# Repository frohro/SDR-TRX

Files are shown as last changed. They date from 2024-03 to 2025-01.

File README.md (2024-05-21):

# SDR-TRX Digital Modes Transceiver, 2023-2024
## Philosophy and Design Goals
This SDR is a prototype hardware platform to assist in developing a low-cost transceiver for digital modes (FT8, JSTcall, WSPR, CW, etc) that do not require linear amplification like SSB.  This is designed for amateur radio enthusiasts who view their hobby as an avenue for experimenting, who like building things, and have an interest in HF radio propagation.  The idea is to use a laptop and mainstream (actively maintained) existing software as the display and for the DSP needed.  The hardware described here will fill out the rest of the transceiver.  The assumption is that most hams will have a PC of some kind already, and this is an easy and cheap way to get on the air using the digital modes and their PC.
I am also using this as a platform to demonstrate to my students how to do an electronic design project.  It is hoped a transceiver based on this prototype platform will be inexpensive enough that third-world hams or those with few funds to spend on their hobby would find it attractive.  JLCPCB built five of these for me for a little over $100.  This project is built using designs previously published and would not be possible without them.  The next section is meant to be a short review of some of the projects I found especially useful.
### Previous Work
#### Especially Relevant Work
* [WSJT-Transceiver](https://github.com/agustinmartino/wsjt_transceiver/blob/master/README.md)
* [Quisk SDR Software](https://james.ahlstrom.name/quisk/)
* [WSJT-X Low S/N Digital Mode Decoding Software](https://wsjt.sourceforge.io/)
* [Fldigi](http://www.w1hkj.com/FldigiHelp/index.html)
* [DL2MAN Sandwich](https://dl2man.de/sample-page/)
* [PE1NNZ uSDX](https://github.com/threeme3/usdx)
* [A Comparison of Affordable Self-Assembled SDR Receivers](https://fweb.wallawalla.edu/~frohro/ClassHandouts/Electronics/A%20Comparison%20of%20Affordable,%20Self-Assembled%20%20Software-Defined%20Radio%20Receivers%20Using%20Quadrature%20Sampling%20Down-Conversion.pdf)
* [QRP Labs QDX Transceiver](https://www.qrp-labs.com/qdx.html) (This transceiver is quite similar.)
#### More General but Useful Work
*  [Easy-Transceiver](https://github.com/kholia/Easy-Transceiver])
* [Etherkit JTEncode](https://github.com/etherkit/JTEncode)
* [Etherkit Si5351](https://github.com/etherkit/Si5351Arduino)

###
The basic block diagram showing how this SDR interfaces with a PC is shown below.  (Sorry the photos do not show up on GitHub's README here.  To see them, download the progress notes here: https://github.com/frohro/SDR-TRX/blob/main/SDR-TRX-Readme-Progress-Notes.html and then open them in your browser, or get the iPython Progress Notes for a more up to date version and use JupyterLab or similar tool to read them.)

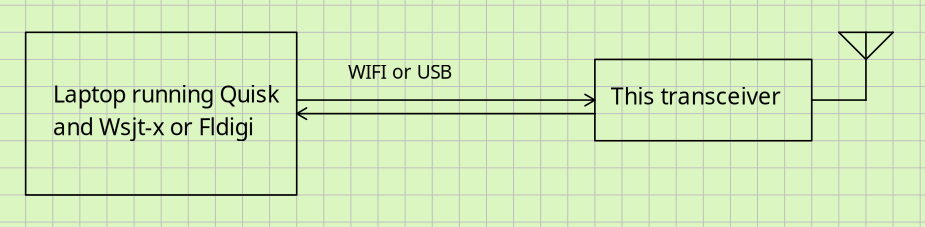
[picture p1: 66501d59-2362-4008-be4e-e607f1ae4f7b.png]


A clone of the Silicon Labs, Si5351a, the MS5351M is used as the local oscillator for the QSD down converter.  The resultant audio frequency data is sent to the PC where Quisk demodulates it and sends it on to WSJT-X or Fldigi for decoding.  The MS5351M's third oscillator is used to generate the digital signals on transmit.  These signals are amplified by a class E circuit for the 20-meter band.  Throughout the unit, there are features that provide stepping stones toward the final goal.  For example, an output is provided to allow the sound data to be sent to the PC where a sound card on the PC converts the sound signal to digital samples.  A Raspberry Pi Pico or Pico W is used on the SDR to control the MS5351M local oscillator and exciter, sample the receiver audio data using a PCM1808 ADC, and send the sampled data to the PC for processing.  It also receives transmit data from the PC to allow transmission of the digital signals desired.

The Kicad project SDR-TRX contains the hardware documentation, including the schematic diagram and the printed circuit board.  The software is still in development.

##  Transmitter 
The MS5351M, a Si5351a clone, generates a digitally transmitted signal (and the harmonics you expect) on its third output.  It is used to drive a set of CMOS inverters that in turn drive a MOSFET class E amplifier for 20 meters. 

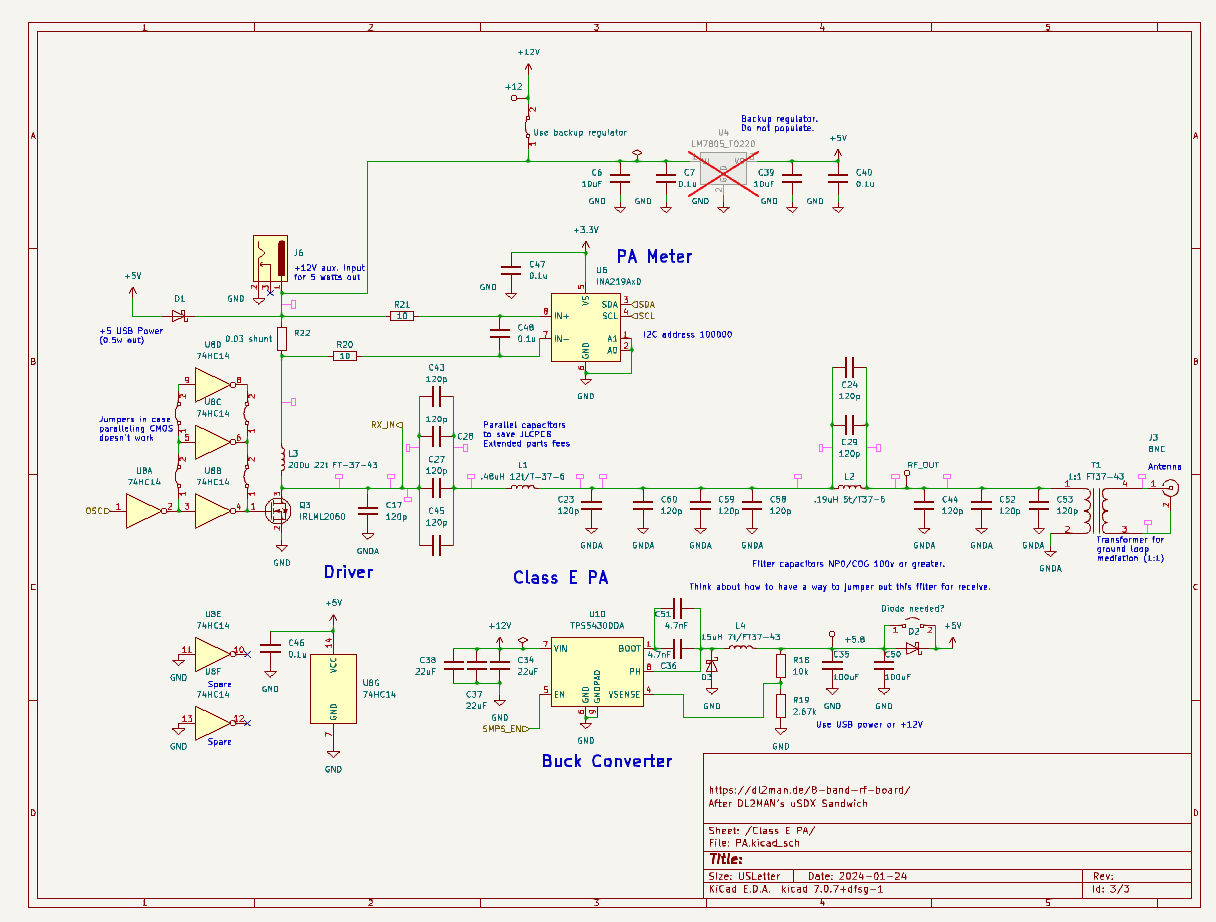
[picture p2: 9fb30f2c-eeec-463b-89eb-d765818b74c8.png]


### Class E Amplifier
The design started with the DL2MAN sandwich Class E amplifier for 20 meters.  LTspice was employed to try and minimize the number of values of Extended Parts capacitors needed from JLCPCB while still maintaining a decent efficiency, power output, and harmonic attenuation.  The value of the capacitor that seemed to be best was a 120 pF 100V 1% COG multilayer monolithic capacitor.  We paralleled a bunch to make the amplifier we ended up with.  It was chosen first for harmonic suppression, second for power output, and lastly for efficiency, with the constraint of using only one value of capacitor.  The simulation has about 50 dB of harmonic attenuation, about a watt of output, and an efficiency of 75%.  See the simulation below which is called Class E.asc in the Simulation folder.

This simulation shows the efficiency and output power.

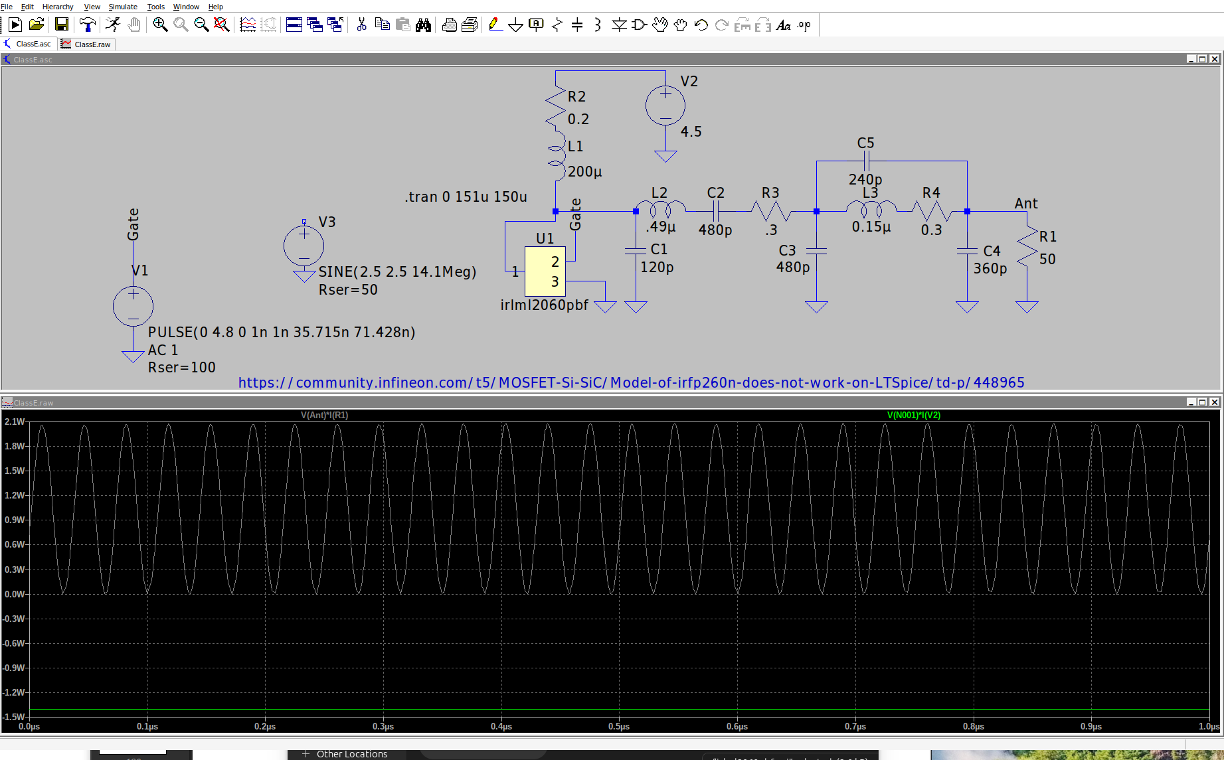
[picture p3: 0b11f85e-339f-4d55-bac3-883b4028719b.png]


This is the FFT of the antenna voltage.
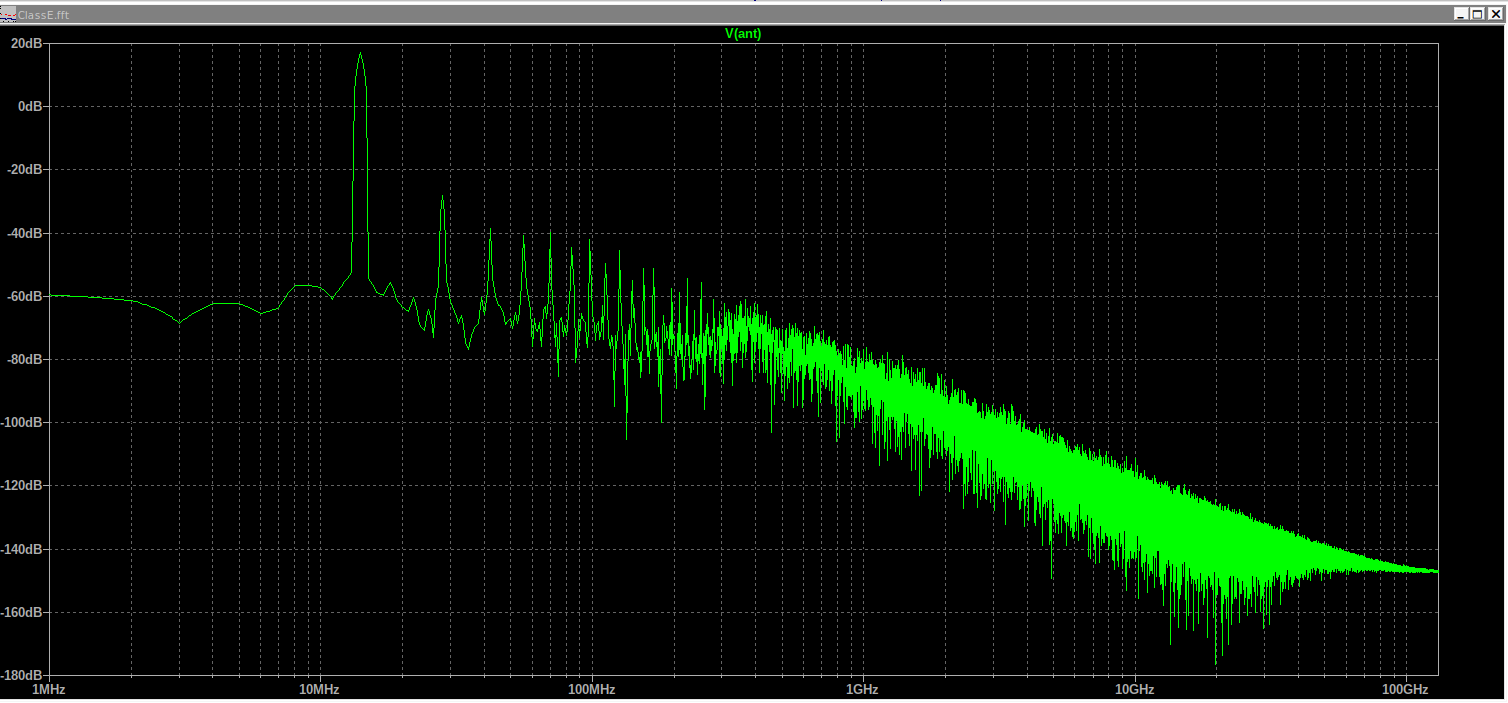
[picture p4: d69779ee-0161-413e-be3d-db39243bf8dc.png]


There is an I2C voltage and current monitor, the INA219A, that should allow measuring the DC power used by the class E amplifier so LTspice simulations can be verified for accuracy easily.

## Receiver
The receiver used was the [QSD Tayloe-type](https://www.norcalqrp.org/files/Tayloe_mixer_x3a.pdf) design using both inverting and inverting inputs.  The inverting input has a lower input impedance and so is more of a current amplifier.  The non-inverting amplifier has a high input impedance, and so acts as a voltage amplifier.  The low-frequency gain of the inverting amplifier is $\frac{-R_f}{R_i}$ and the non-inverting amplifier has a gain of $1 + \frac{R_f}{R_i}$ so the CMRR is  not as good as a fully differential amplifier, but we are just trying to amplify the signal not null out any common mode signal.  We need to keep the DC to $\frac {4.5V}{2}$ and the $1$ term perfectly does this for us for the common mode DC voltage.  There is a gain for the mixer of $1/4$ because the state space average of the switched voltage at the output of the mixer is a quarter of the input voltage.  The gain is initially set to about 20 between the antenna and I or Q.  These signals go into the soundcard or the onboard ADC, a PCM1808.

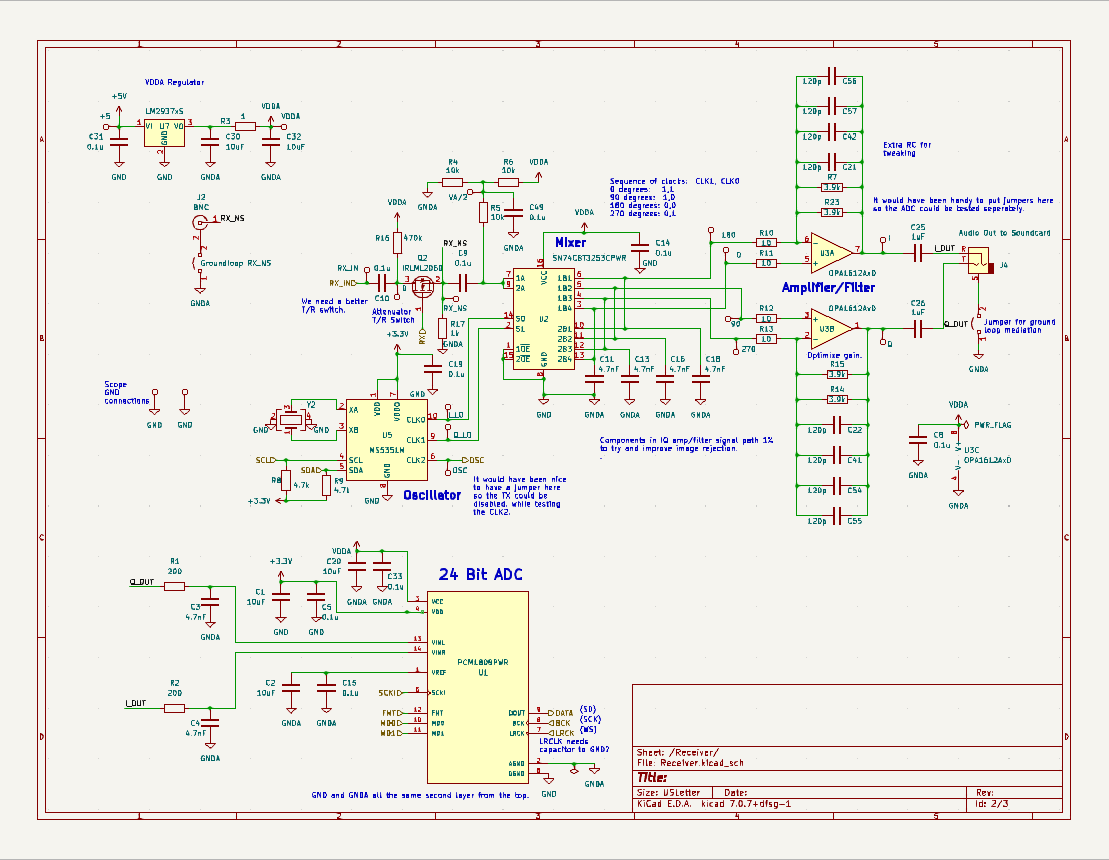
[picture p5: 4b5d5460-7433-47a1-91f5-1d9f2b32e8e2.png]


The MS5351M generates in-phase and quadrature signals for the SN74CBT3253 four-to-one analog switch mixer.

The sampling capacitors provide a low pass filter for the signal, and the cutoff frequency is $1/(2\pi R_f 4 C)$.  The factor of four comes about because the sampling capacitors only get charged a quarter of the time, or equivalently, there are four of them to charge.  The resistance, $R_i$, is the antenna impedance plus the 10 ohms on the inverting input.  The feedback capacitors, $C_f$ add another pole of low pass filter to the signal.  The cutoff frequency of these filters is $1/(2\pi R_f C_f)$.

There are two antenna inputs (BNC connectors), one on a transmit/receive switch that uses the Class E filter to try and filter the received signal, and another one that bypasses the filter that can be used when we want to listen to more than just 20 meters.  It can also suffice to do real-world testing to see which is preferable.

An LDO linear regulator powered by the USB 5 volts or the external 12-volt power supply provides a 4.5 volt low noise power for the analog parts in the receiver.  When the 12-volt input is used the USB power supply is disconnected by some Schottky diodes and two possible regulators drop the voltage to about 5.8 volts to run the rest of the radio except the class E PA stage.  These are selected by an I/O line from the processor or by not populating the undesired supply.  The two options are an SMPS buck regulator or a 7805 linear regulator that is not as efficient but should not produce switching noise. We will experiment to see which we like and choose that one.

There are several ground loop suppression strategies available.  The filtered antenna uses a transformer.  In other places, a jumper is provided to allow a single ground connection through the power supply.  

## Control Circuitry
The control of the SDR comes from the operator via the PC interface software (Quisk, for example), which sends the data to the SDR via USB UART or via WIFI.  The MCU that we chose is the Raspberry Pi Pico or Pico W if WIFI is desired.  It controls the MS5351M programmable oscillator using I2C and uses the INA219 to measure the current and voltage of the power amplifier.  It also reads the ADC via I2S and transfers that data to the PC where Quisk or a similar program demodulates it.  For the Pico, we are using C++ and the Earl E. Philhower, [Arduido-Pico](https://arduino-pico.readthedocs.io/en/latest/index.html) development library.  The easiest way to get started is to use the Arduino IDE, but VScode with Github Copilot there are a lot more features.  You have to [read how to make the Arduino-Pico](https://arduino-pico.readthedocs.io/en/latest/platformio.html) code work with VScode.  The software needs a lot more attention, but that is the point of a software-defined radio.

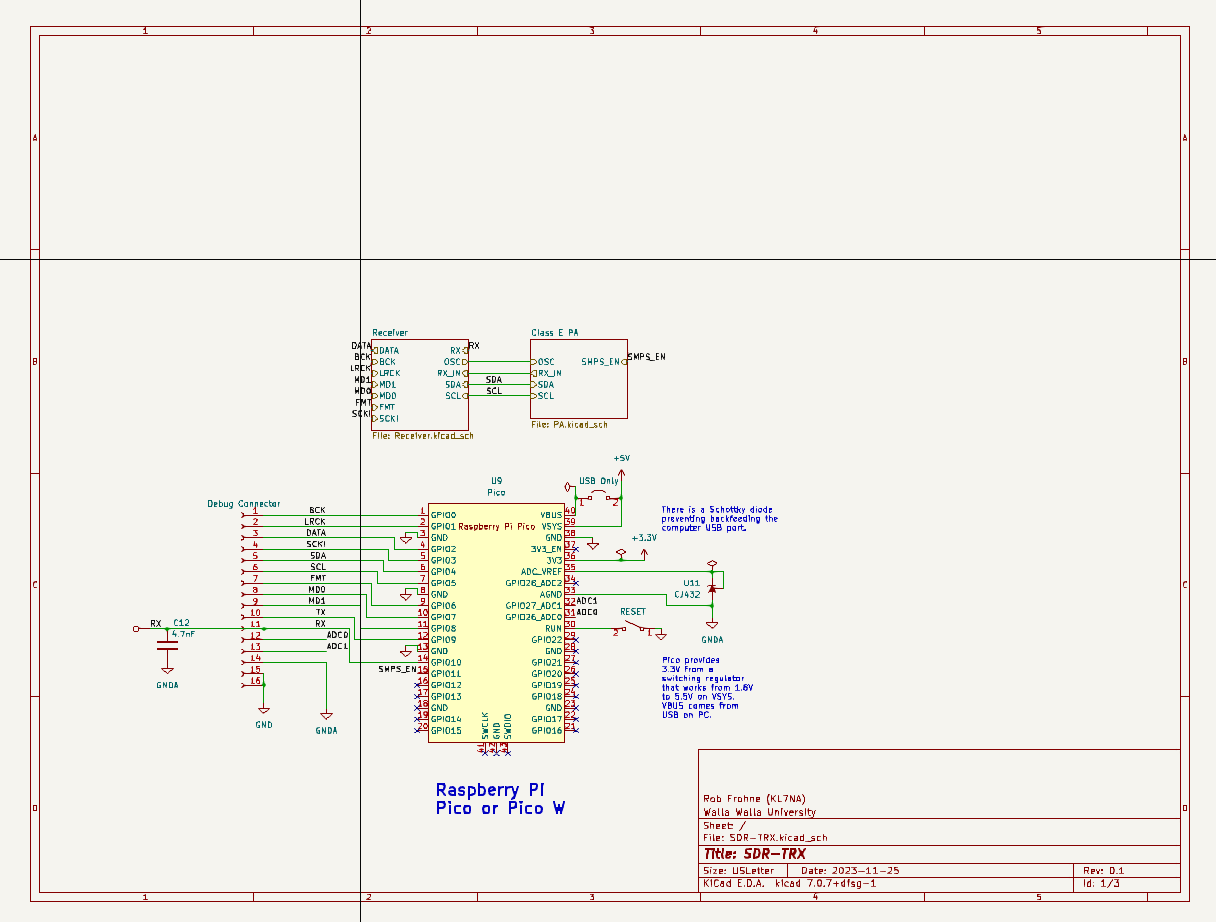
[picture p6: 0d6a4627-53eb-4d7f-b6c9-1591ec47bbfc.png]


### PCB
The PCB has test points and uses components I found still available on JLCPCB.  That accounts for why a mix or 0603 and 0805 components, and why there are a lot of 120pF and 4.7nF caps in parallel.

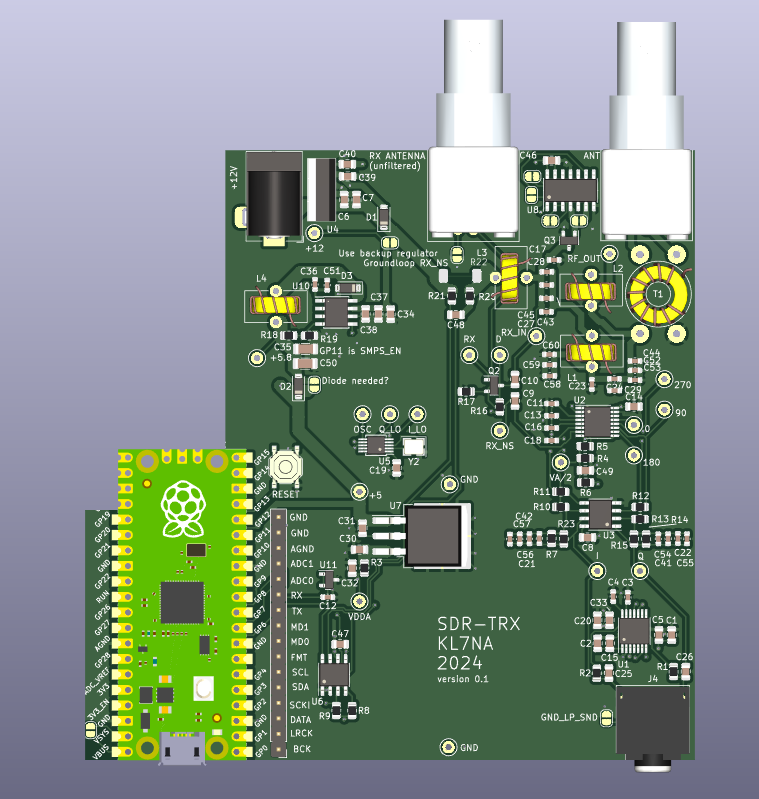
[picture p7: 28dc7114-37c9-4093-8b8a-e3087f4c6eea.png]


The cutout is for the WIFI antenna if a Pico W is used.

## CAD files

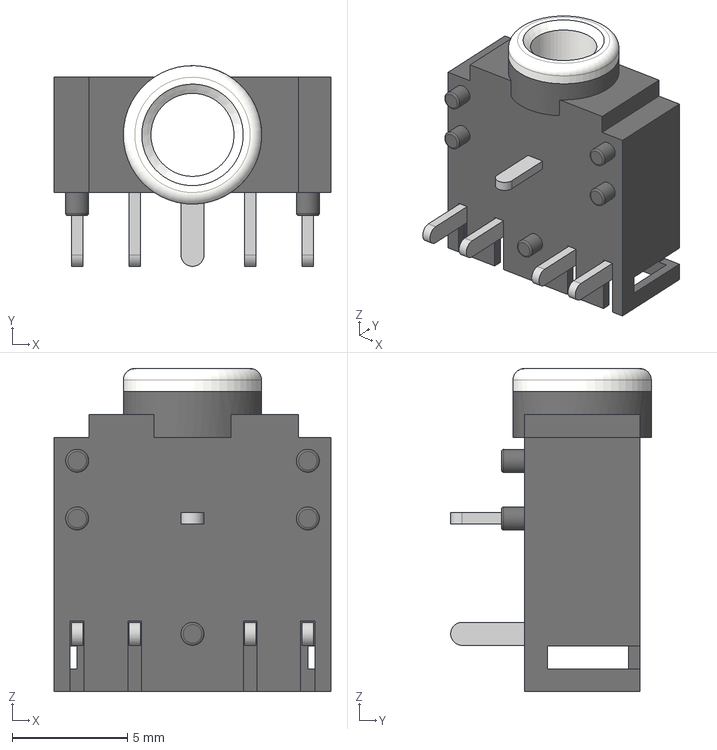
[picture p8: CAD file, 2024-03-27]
Hardware/pj-307.step
12.0 x 8.70 x 14.0 mm

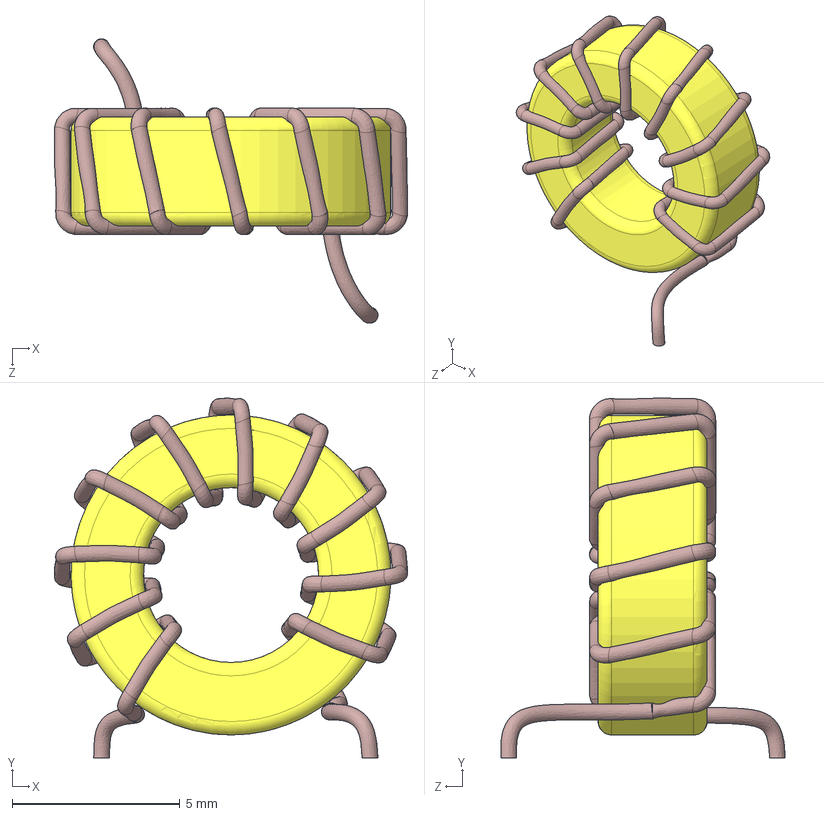
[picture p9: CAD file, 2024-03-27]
Hardware/T37-6 IND.STEP
10.5 x 10.7 x 8.47 mm

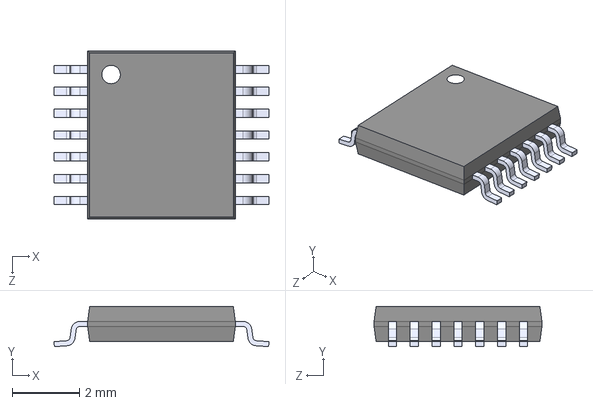
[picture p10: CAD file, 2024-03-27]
Hardware/PCM1808PWR.step
6.40 x 1.20 x 5.00 mm

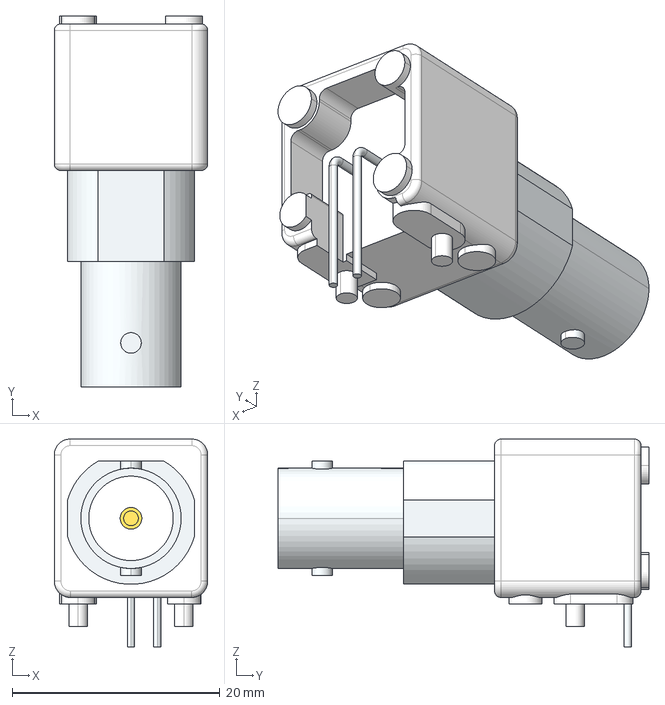
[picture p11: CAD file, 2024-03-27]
Hardware/1564889-62.stp
14.8 x 35.7 x 20.0 mm

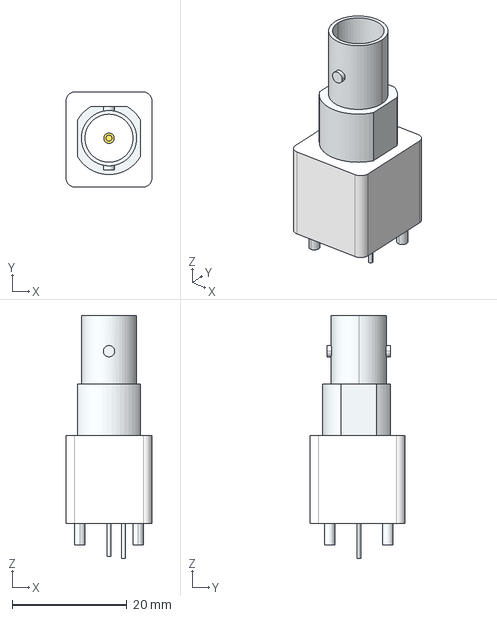
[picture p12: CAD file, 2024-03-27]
Hardware/1566143-62.stp
15.0 x 16.6 x 42.4 mm

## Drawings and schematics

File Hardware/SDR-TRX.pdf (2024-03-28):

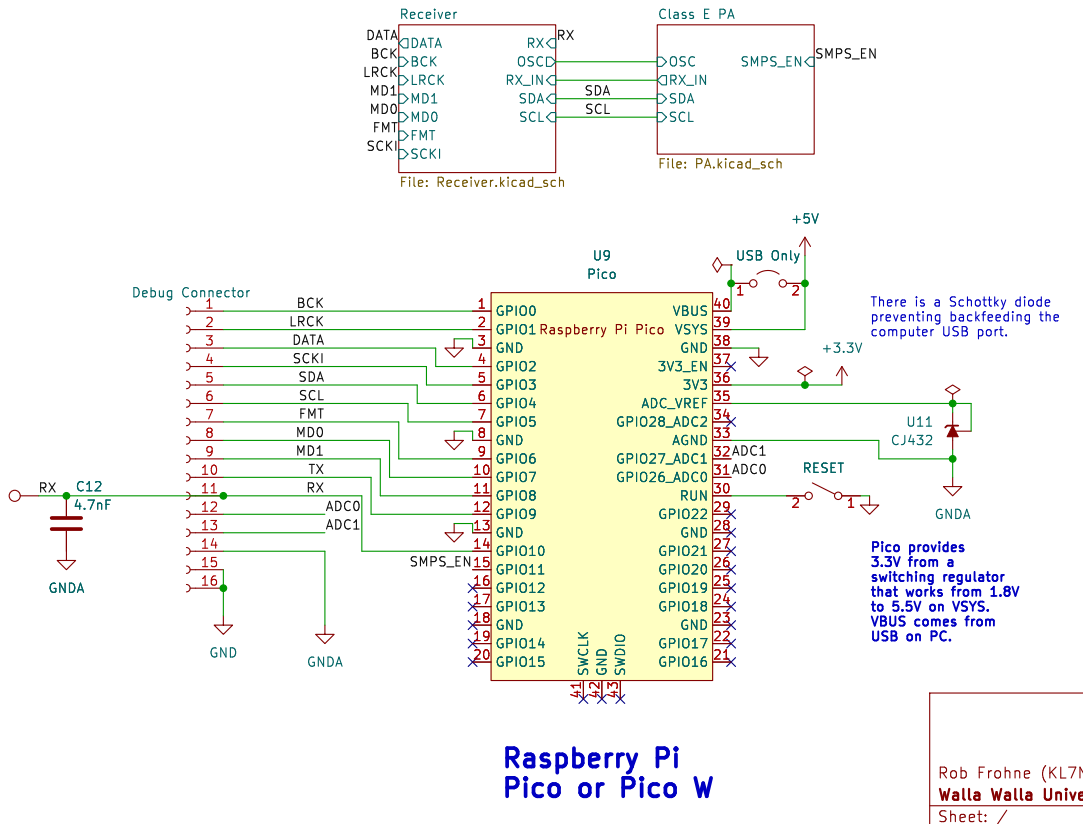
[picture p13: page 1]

There is a Schottky diode

3.3V from a
switching regulator
that works from 1.8V
to 5.5V on VSYS. VBUS comes from

Id: 1/3 Title: SDR-TRX

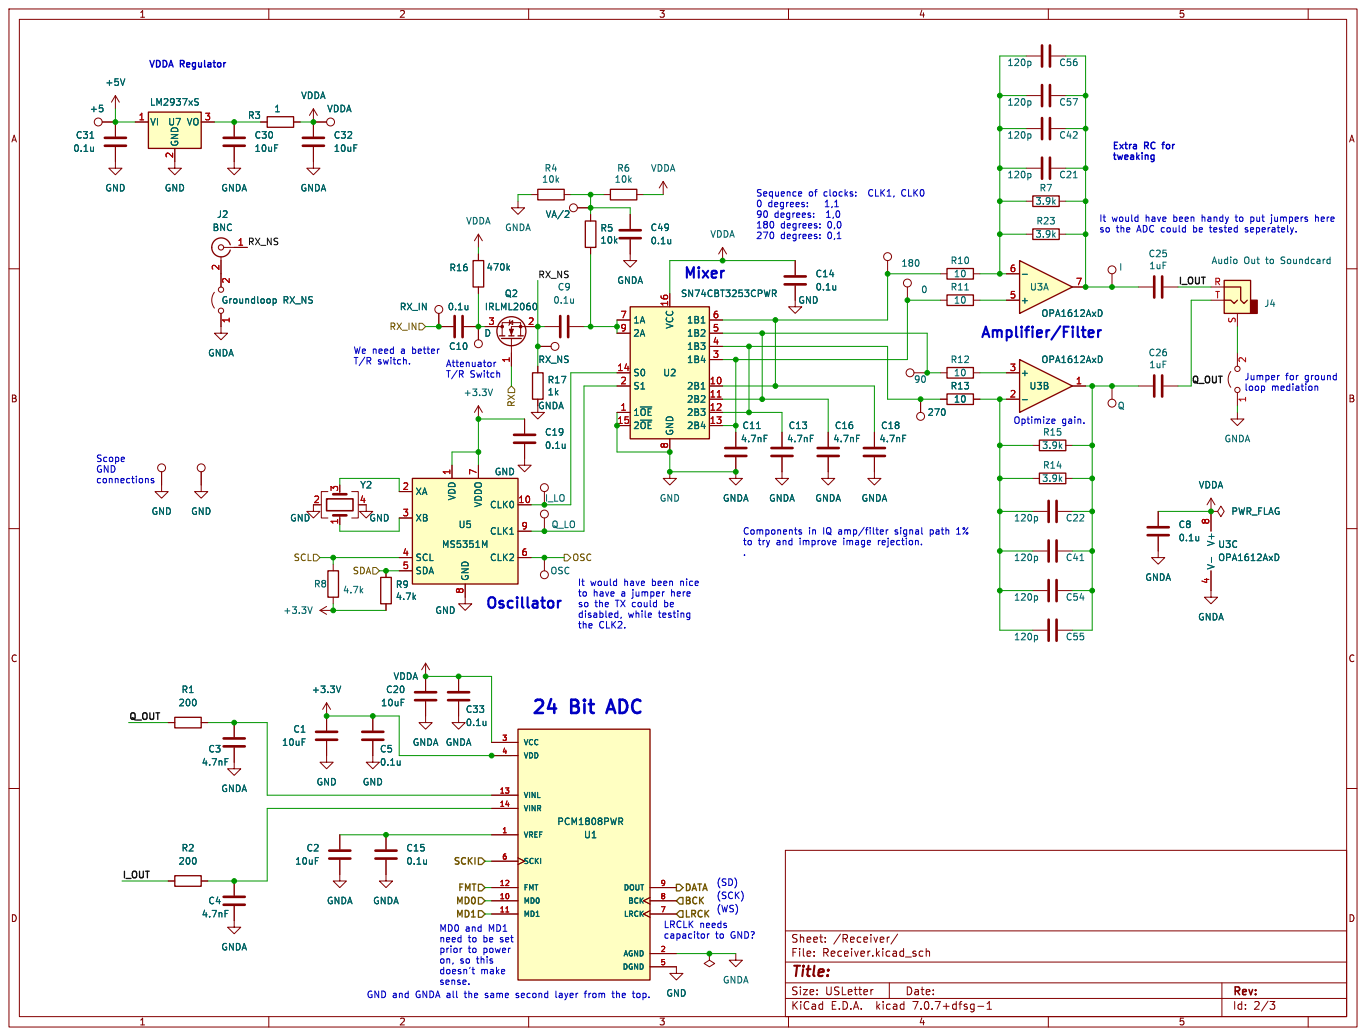
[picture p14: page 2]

J4 Audio Out to Soundcard R17

It would have been handy to put jumpers here
so the ADC could be tested seperately.

. Mixer GND and GNDA all the same second layer from the top. MD0 and MD1

1 CLK0 10 XA 2 XB 3 SCL 4 SDA 5 CLK2 6 VDDO

to try and improve image rejection.

It would have been nice
to have a jumper here
so the TX could be
the CLK2.

Id: 2/3 Title: File: Receiver.kicad_sch Sheet: /Receiver/

need to be set prior to power on, so this doesn't make

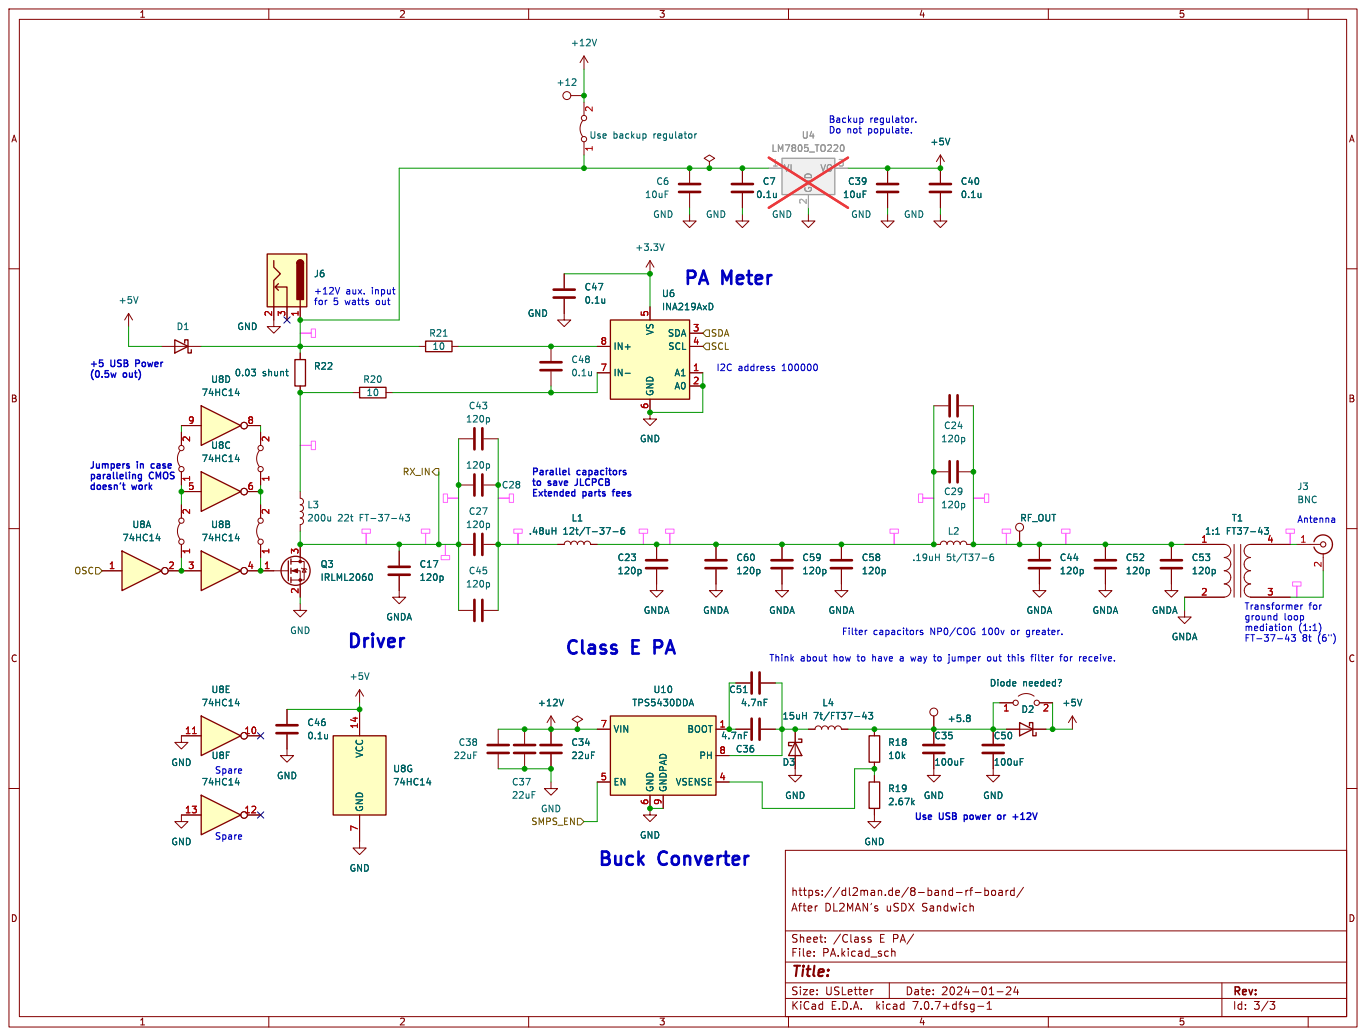
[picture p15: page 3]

Backup regulator. Do not populate.
+5V GND

https://dl2man.de/8-band-rf-board/

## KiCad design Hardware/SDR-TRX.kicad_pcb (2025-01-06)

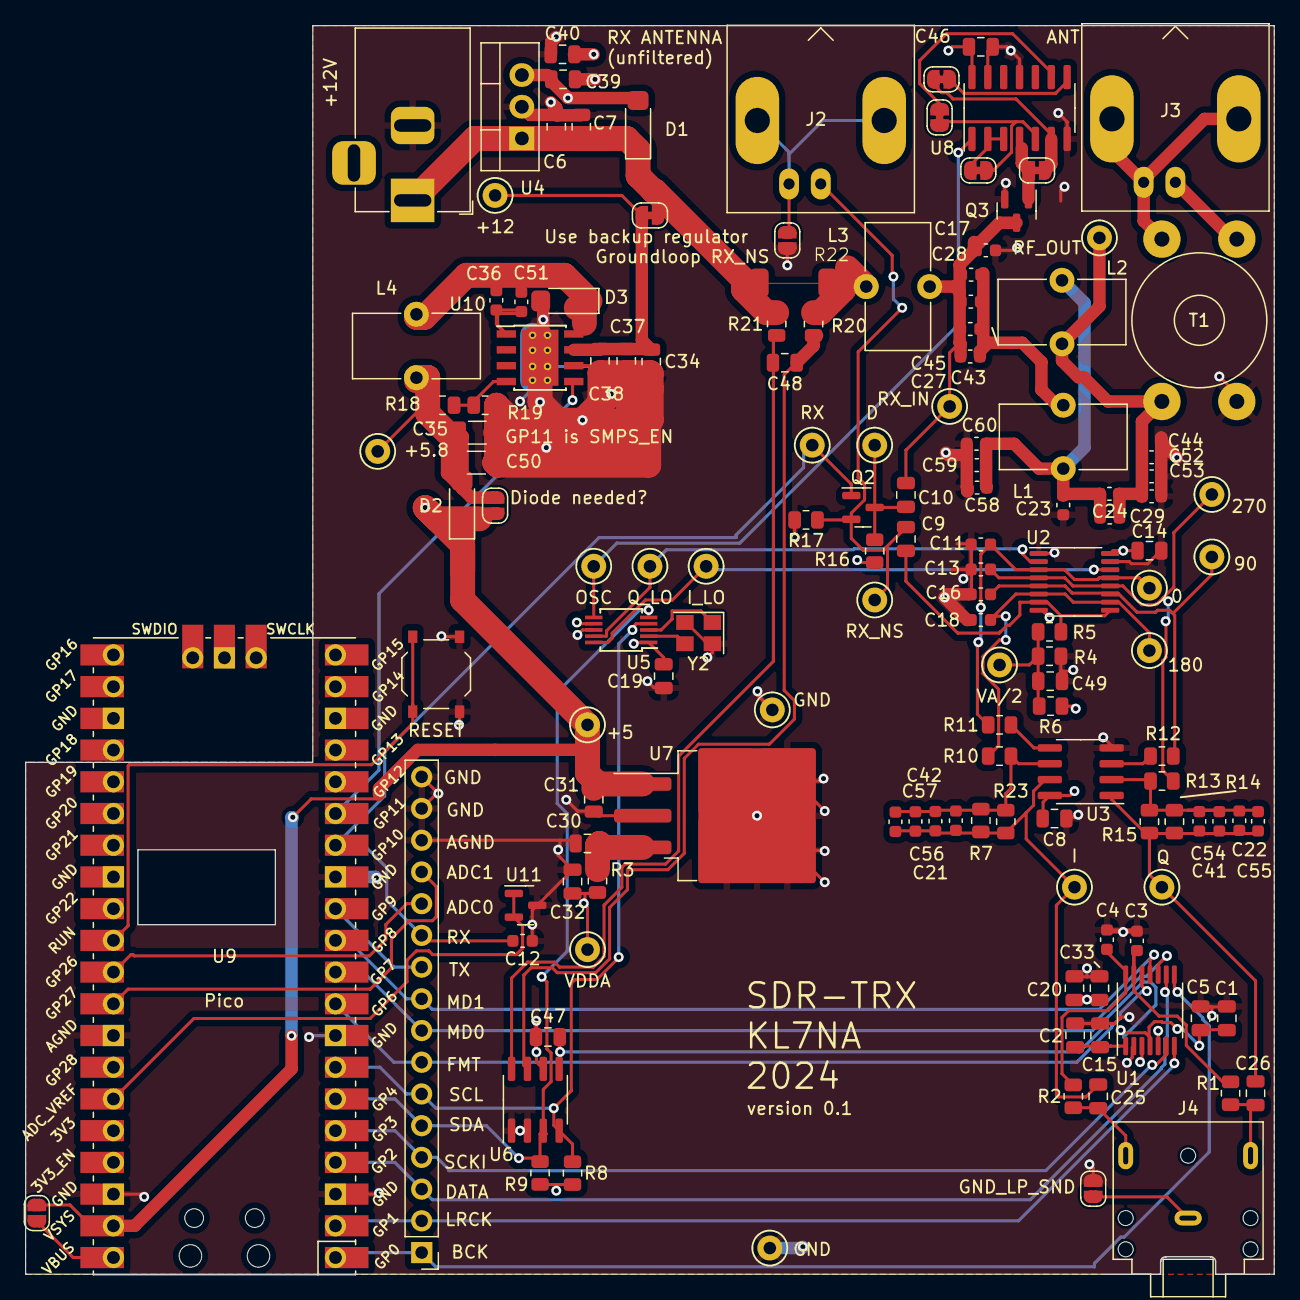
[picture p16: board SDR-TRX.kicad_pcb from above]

Board: 4 copper layers, 100.0 x 100.0 mm, 141 parts (0 on the bottom side), 69 nets.

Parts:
C1, C2, C6, C20, C30, C32, C39: 10uF; C_0805_2012Metric
C3, C4, C11, C12, C13, C16, C18, C36, C51: 4.7nF; C_0603_1608Metric
C5, C7, C8, C9, C10, C14, C15, C19, C31, C33, C40, C46, C47, C48, C49: 0.1u; C_0805_2012Metric
C17, C21, C22, C23, C24, C27, C28, C29, C41, C42, C43, C44, C45, C52, C53, C54, C55, C56, C57, C58, C59, C60: 120p; C_0603_1608Metric
C25, C26: 1uF; C_0805_2012Metric
C34, C37, C38: 22uF; C_0805_2012Metric
C35, C50: 100uF; C_1206_3216Metric
D1, D2, D3: SS54; DO-214AC-Rob
J1: Debug Connector; PinHeader_1x16_P2.54mm_Vertical
J2, J3: BNC; BNC_Amphenol_B6252HB-NPP3G-50_Horizontal
J4: Audio Out to Soundcard; Jack_3.5mm_CUI_SJ1-3523N_Horizontal
J6: +12V; BarrelJack_Horizontal
JP1: GND_LP_SND; SolderJumper-2_P1.3mm_Open_RoundedPad1.0x1.5mm
JP2: Groundloop RX_NS; SolderJumper-2_P1.3mm_Open_RoundedPad1.0x1.5mm
JP4: Use backup regulator; SolderJumper-2_P1.3mm_Bridged_RoundedPad1.0x1.5mm
JP5: CM1A; SolderJumper-2_P1.3mm_Bridged_RoundedPad1.0x1.5mm
JP6: CM1B; SolderJumper-2_P1.3mm_Bridged_RoundedPad1.0x1.5mm
JP7: CM2B; SolderJumper-2_P1.3mm_Bridged_RoundedPad1.0x1.5mm
JP8: CM2A; SolderJumper-2_P1.3mm_Bridged_RoundedPad1.0x1.5mm
JP9: Diode needed?; SolderJumper-2_P1.3mm_Open_RoundedPad1.0x1.5mm
JP12: USB Only; SolderJumper-2_P1.3mm_Open_RoundedPad1.0x1.5mm
L1: .48uH 12t/T-37-6; L_Toroid_Vertical_L10.0mm_W5.0mm_P5.08mm
L2: .19uH 5t/T37-6; L_Toroid_Vertical_L10.0mm_W5.0mm_P5.08mm
L3: 200u 22t FT-37-43; L_Toroid_Vertical_L10.0mm_W5.0mm_P5.08mm
L4: 15uH 7t/FT37-43; L_Toroid_Vertical_L10.0mm_W5.0mm_P5.08mm
Q2, Q3: IRLML2060; SOT-23
R1, R2: 200; R_0805_2012Metric
R3: 1; R_0805_2012Metric
R4, R5, R6, R18: 10k; R_0805_2012Metric
R7, R14, R15, R23: 3.9k; R_0805_2012Metric
R8, R9: 4.7k; R_0805_2012Metric
R10, R11, R12, R13, R20, R21: 10; R_0805_2012Metric
R16: 470k; R_0805_2012Metric
R17: 1k; R_0805_2012Metric
R19: 2.67k; R_0805_2012Metric
R22: 0.03 shunt; .03 Shunt
SW2: RESET; SW_Push_1P1T_XKB_TS-1187A
T1: 1:1 FT37-43; Transformer_Toroid_Horizontal_D10.5mm_Amidon-T37
TP1: I_LO; TestPoint_Keystone_5000-5004_Miniature
TP2: Q_LO; TestPoint_Keystone_5000-5004_Miniature
TP4: RX_NS; TestPoint_Keystone_5000-5004_Miniature
TP5: 180; TestPoint_Keystone_5000-5004_Miniature
TP6: 0; TestPoint_Keystone_5000-5004_Miniature
TP7: 270; TestPoint_Keystone_5000-5004_Miniature
TP8: 90; TestPoint_Keystone_5000-5004_Miniature
TP9, TP13: GND; TestPoint_Keystone_5000-5004_Miniature
TP10: I; TestPoint_Keystone_5000-5004_Miniature
TP11: Q; TestPoint_Keystone_5000-5004_Miniature
TP12: VA/2; TestPoint_Keystone_5000-5004_Miniature
TP14: RX_IN; TestPoint_Keystone_5000-5004_Miniature
TP15: D; TestPoint_Keystone_5000-5004_Miniature
TP16: OSC; TestPoint_Keystone_5000-5004_Miniature
TP17: RX; TestPoint_Keystone_5000-5004_Miniature
TP18: RF_OUT; TestPoint_Keystone_5000-5004_Miniature
TP27: VDDA; TestPoint_Keystone_5000-5004_Miniature
TP28: +5; TestPoint_Keystone_5000-5004_Miniature
TP34: +5.8; TestPoint_Keystone_5000-5004_Miniature
TP35: +12; TestPoint_Keystone_5000-5004_Miniature
U1: PCM1808PWR; TSSOP-14_4.4x5mm_P0.65mm
U2: SN74CBT3253CPWR; TSSOP-16_4.4x5mm_P0.65mm
U3: OPA1612AxD; SOIC-8_3.9x4.9mm_P1.27mm
U4: LM7805_TO220; TO-220-3_Vertical
U5: MS5351M; MSOP-10_3x3mm_P0.5mm
U6: INA219AxD; SOIC-8_3.9x4.9mm_P1.27mm
U7: LM2937xS; TO-263-3_TabPin2
U8: 74HC14; SOIC-14_3.9x8.7mm_P1.27mm
U9: Pico; RPi_Pico_SMD_TH
U10: TPS5430DDA; TI_SO-PowerPAD-8_ThermalVias
U11: CJ432; SOT-23
Y2: X322525MSB4SI; Crystal_SMD_3225-4Pin_3.2x2.5mm

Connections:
+3.3V: C1.1, C5.2, C19.2, C47.2, R8.2, R9.2, U1.4 (VDD), U5.1 (VDD), U5.7 (VDDO), U6.5 (VS), U9.36 (3V3)
+5V: C31.1, C39.1, C40.2, C46.2, D1.2 (A), D2.1 (K), JP9.2 (B), JP12.2 (B), TP28.1, U4.3 (VO), U7.1 (VI), U8.14 (VCC), U9.39 (VSYS)
+12V: C34.1, C37.1, C38.1, JP4.2 (B), TP35.1, U10.7 (VIN)
/ADC0: J1.12, U9.31 (GPIO26_ADC0)
/ADC1: J1.13, U9.32 (GPIO27_ADC1)
/BCK: J1.1, U1.8 (BCK), U9.1 (GPIO0)
/Class E PA/OSC: TP16.1, U5.6 (CLK2), U8.1
/Class E PA/RX_IN: C10.1, C17.2, C27.2, C28.2, C43.2, C45.2, L3.2, Q3.3 (D), TP14.1
/DATA: J1.3, U1.9 (DOUT), U9.4 (GPIO2)
/FMT: J1.7, U1.12 (FMT), U9.9 (GPIO6)
/LRCK: J1.2, U1.7 (LRCK), U9.2 (GPIO1)
/MD0: J1.8, U1.10 (MD0), U9.10 (GPIO7)
/MD1: J1.9, U1.11 (MD1), U9.11 (GPIO8)
/RX: C12.2, J1.11, Q2.1 (G), TP17.1, U9.14 (GPIO10)
/Receiver/I_OUT: C25.1, J4.R, R2.1
/Receiver/Q_OUT: C26.1, J4.T, R1.1
/Receiver/RX_NS: C9.1, J2.1 (In), Q2.2 (S), R17.1, TP4.1
/SCKI: J1.4, U1.6 (SCKI), U9.5 (GPIO3)
/SCL: J1.6, R8.1, U5.4 (SCL), U6.4 (SCL), U9.7 (GPIO5)
/SDA: J1.5, R9.1, U5.5 (SDA), U6.3 (SDA), U9.6 (GPIO4)
/SMPS_EN: U9.15 (GPIO11), U10.5 (EN)
/TX: J1.10, U9.12 (GPIO9)
GND: C1.2, C2.2, C3.1, C4.1, C5.1, C6.2, C7.1, C8.1, C11.1, C12.1, C13.1, C14.1, C15.1, C16.1, C17.1, C18.1, C19.1, C20.2, C23.2, C30.2, C31.2, C32.2, C33.1, C34.2, C35.2, C37.2, C38.2, C39.2, C40.1, C44.2, C46.1, C47.1, C49.1, C50.2, C52.2, C53.2, C58.2, C59.2, C60.2, D3.2 (A), J1.14, J1.15, J1.16, J6.2, JP1.1 (A), JP2.1 (A), Q3.2 (S), R4.2, R17.2, R19.2, SW2.1 (A), T1.2 (AB), TP9.1, TP13.1, U1.2 (AGND), U1.5 (DGND), U2.1 (1~OE), U2.8 (GND), U2.15 (2~OE), U3.4 (V-), U4.2 (GND), U5.8 (GND), U6.1 (A1), U6.2 (A0), U6.6 (GND), U7.2 (GND), U8.7 (GND), U8.11, U8.13, U9.3 (GND), U9.8 (GND), U9.13 (GND), U9.33 (AGND), U9.38 (GND), U10.6 (GND), U10.9 (GNDPAD), U11.3 (A), Y2.2, Y2.4
unnamed: C21.2, C25.2, C42.2, C56.2, C57.2, R7.1, R23.1, TP10.1, U3.7
unnamed: C22.2, C26.2, C41.2, C54.2, C55.2, R14.1, R15.1, TP11.1, U3.1
unnamed: C23.1, C24.2, C29.2, C58.1, C59.1, C60.1, L1.2, L2.1
unnamed: C27.1, C28.1, C43.1, C45.1, L1.1
unnamed: C49.2, R4.1, R5.1, R6.2, TP12.1
unnamed: C6.1, C7.2, D1.1 (K), J6.1, JP4.1 (A), R21.2, R22.2, U4.1 (VI)
unnamed: C35.1, C50.1, D2.2 (A), JP9.1 (A), L4.2, R18.1, TP34.1
unnamed: C36.1, C51.1, D3.1 (K), L4.1, U10.8 (PH)
unnamed: J2.2 (Ext), JP2.2 (B)
unnamed: J3.2 (Ext), T1.3 (SA)
unnamed: J3.1 (In), T1.4 (SB)
unnamed: J4.S, JP1.2 (B)
unnamed: JP5.1 (A), U8.2, U8.3
unnamed: JP5.2 (B), JP8.1 (A), U8.5
unnamed: JP6.1 (A), Q3.1 (G), U8.4
unnamed: JP6.2 (B), JP7.1 (A), U8.6
unnamed: JP7.2 (B), U8.8
unnamed: JP8.2 (B), U8.9
unnamed: JP12.1 (A), U9.40 (VBUS)
unnamed: L3.1, R20.2, R22.1
unnamed: C10.2, Q2.3 (D), R16.2, TP15.1
unnamed: SW2.2 (B), U9.30 (RUN)
unnamed: C24.1, C29.1, C44.1, C52.1, C53.1, L2.2, T1.1 (AA), TP18.1
unnamed: C3.2, R1.2, U1.13 (VINL)
unnamed: C4.2, R2.2, U1.14 (VINR)
unnamed: C2.1, C15.2, U1.1 (VREF)
unnamed: C9.2, R5.2, U2.7 (1A), U2.9 (2A)
unnamed: C18.2, R10.2, TP5.1, U2.6 (1B1), U2.10 (2B1)
unnamed: C16.2, R12.2, TP8.1, U2.5 (1B2), U2.11 (2B2)
unnamed: C13.2, R13.2, TP7.1, U2.4 (1B3), U2.12 (2B3)
unnamed: C11.2, R11.2, TP6.1, U2.3 (1B4), U2.13 (2B4)
unnamed: TP1.1, U2.14 (S0), U5.10 (CLK0)
unnamed: TP2.1, U2.2 (S1), U5.9 (CLK1)
unnamed: R12.1, U3.3 (+)
unnamed: C22.1, C41.1, C54.1, C55.1, R13.1, R14.2, R15.2, U3.2 (-)
unnamed: R11.1, U3.5 (+)
unnamed: C21.1, C42.1, C56.1, C57.1, R7.2, R10.1, R23.2, U3.6 (-)
unnamed: U5.2 (XA), Y2.3
unnamed: U5.3 (XB), Y2.1
unnamed: C48.2, R21.1, U6.8 (IN+)
unnamed: C48.1, R20.1, U6.7 (IN-)
unnamed: C30.1, R3.2, U7.3 (VO)
unnamed: C36.2, C51.2, U10.1 (BOOT)
unnamed: R18.2, R19.1, U10.4 (VSENSE)
unnamed: U9.35 (ADC_VREF), U11.1 (REF), U11.2 (K)
VDDA: C8.2, C14.2, C20.1, C32.1, C33.2, R3.1, R6.1, R16.1, TP27.1, U1.3 (VCC), U2.16 (VCC), U3.8 (V+)

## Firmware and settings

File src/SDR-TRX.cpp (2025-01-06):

/*
 * This Pico W program will connect to the PCM1808 via I2S and read the data it rate samples per second.
 * It then sends the data over WIFI using UDP.  To receive it and plot the results, you can use the
 * python scripts and this sequence in Linux:
 * $ rm sound_data.csv
 * $ nc -u -l 12345 > sound_data.csv
 * ^C
 * $ python3 plot_sound_data.py
 * The ^C is to stop the nc process which is receiving the data and saving it to sound_data.csv.
 * You can see that every once in a while there will be what appears to be a zero in the data.
 * We will have to remove them.  We also have to remove about 90 samples every second at 96 kHz
 * sampling rate.  (Less at slower sampling rates, because the Pico does not have exactly the right
 * crystal frequency to get exactly the audio rate we need.  We could reduce the load on the network
 * by sending the data in a binary way.  It appears we are getting almost 3.2 Mbits/s through the
 * WIFI.  This is what the Monitor says, but I calculate 20 Mbit/s.  Why? I think our tests at 96 kHz
 * were flawed, and not correct, as I connot reproduce them.
 *
 * Author: Rob Frohne, KL7NA, with help from Perplexity and Github Copilot.
 * 3/9/2024
 */
#include <Arduino.h>
#include <Wire.h>
#include <I2S.h>
#include <WiFi.h>
#include <WiFiUdp.h>
#include <si5351.h>
#include <JTEncode.h>
#include <pico/mutex.h>
#include "PCM1808_I2S_UDP.h"

// To do:
// 1) We need to add I2C code eand calibrate thu INA219.
// 2) Refactor this into a library so you can do a receiver, transmitter
// or transceiver.  Use OOP.  Make the code maintainable..

// These are things you might want to change for your situation.
const int RATE = 48000;              // Your network needs to handle this, but 96000 should also work, but misses some packets.
const int BITS_PER_SAMPLE_SENT = 16; // 24 or 32, 32 is less packet loss for some strange reason.
const int MCLK_MULT = 256; 
const int MD0 = 7;
const int MD1 = 8;          //
// const char *STASSID = "rosbots";
// const char *PASSWORD = "ros2bots"; // In case you have a password,
// you must add this to the WiFi.begin() call, or if you have no
// password, you need to take the PASSWORD arguement out.
const unsigned int DATA_UDPPORT = 12345;
const unsigned int COMMAND_UDPPORT = 12346;
const unsigned int BROADCAST_UDP_PORT = 12347;
const char *VERSION_NUMBER = "0.1.1";
IPAddress quiskIP(192, 168, 1, 35); // This is the IP address of the computer running Quisk.
// It will be replaced with the IP of the computer that sends the command.
// Radio specific parameters go here.
const int FREQ_LIMIT_LOWER = 3500000;
const int FREQ_LIMIT_UPPER = 30000000;
const int RX_SWITCH = 10;          // GPIO pin for RX/TX switch (High is RX)
const int SMPS_ENABLE = 11;        // GPIO pin for SMPS enable
const int CAL_FACTOR = 1.000; // Calibration factor for the Si5351 (multiply by this number to get the right frequency)
//  I need to put this into Quisk, using the option of my own widgets file.  Then let's remove it from here.
uint_fast32_t rx_freq = 14074000;  // 20 meter FT8 frequency
uint_fast32_t tx_freq = 14074000;  // 20 meter FT8 frequency
int rx_relay_state = 0;            // 0 is RX, 1 is TX
int tx_state = 0;                  // 0 is off, 1 is on
bool data_sending = false;         // Are we sending data over UDP?
bool useUDP = true;               // If false, use UART instead of UDP.
const int SERIAL_TIMEOUT = 20000;  // 20 seconds
WiFiUDP udpData;                   // UDP object for data packets  (Is this a server or a client?)
WiFiUDP udpCommand;                // UDP object for control packets

Si5351 si5351(0x60); // 0x60 is the normal I2C address for the Si5351A or MS5351M

CircularBufferQueue bufferQueue;

// Mode defines
const int JT9_TONE_SPACING = 174;  // ~1.74 Hz
const int JT65_TONE_SPACING = 269; // ~2.69 Hz
const int JT4_TONE_SPACING = 437;  // ~4.37 Hz
const int WSPR_TONE_SPACING = 146; // ~1.46 Hz
const int FSQ_TONE_SPACING = 879;  // ~8.79 Hz
const int FT8_TONE_SPACING = 625;  // ~6.25 Hz
const int FT4_TONE_SPACING = 2083; // ~20.83 Hz

const int JT9_DELAY = 576;     // Delay value for JT9-1
const int JT65_DELAY = 371;    // Delay in ms for JT65A
const int JT4_DELAY = 229;     // Delay value for JT4A
const int WSPR_DELAY = 682;    // Delay value for WSPR
const int FSQ_2_DELAY = 500;   // Delay value for 2 baud FSQ
const int FSQ_3_DELAY = 333;   // Delay value for 3 baud FSQ
const int FSQ_4_5_DELAY = 222; // Delay value for 4.5 baud FSQ
const int FSQ_6_DELAY = 167;   // Delay value for 6 baud FSQ
const int FT8_DELAY = 157;     // Delay value for FT8
const int FT4_DELAY = 45;      // Need to substract 3ms due to PLL delay

const int FT4_SYMBOL_COUNT = 103; // 105?   https://wsjt.sourceforge.io/FT4_FT8_QEX.pdf

const uint_fast32_t JT9_DEFAULT_FREQ = 14078700UL;
const uint_fast32_t JT65_DEFAULT_FREQ = 14078300UL;
const uint_fast32_t JT4_DEFAULT_FREQ = 14078500UL;
const uint_fast32_t WSPR_DEFAULT_FREQ = 14038600UL;
const uint_fast32_t FSQ_DEFAULT_FREQ = 14005350UL; // Base freq is 1350 Hz higher than dial freq in USB
const uint_fast32_t FT8_DEFAULT_FREQ = 14074000UL;
const uint_fast32_t FT4_DEFAULT_FREQ = 14047500UL;

// Enumerations
enum mode
{
  MODE_JT9,
  MODE_JT65,
  MODE_JT4,
  MODE_WSPR,
  MODE_FSQ_2,
  MODE_FSQ_3,
  MODE_FSQ_4_5,
  MODE_FSQ_6,
  MODE_FT8,
  MODE_FT4
};
mode DEFAULT_MODE = MODE_FT8;

uint16_t offset = 1200; // Baseband offset in Hz
uint8_t tx_buffer[255];
enum mode cur_mode = DEFAULT_MODE;
uint8_t symbol_count;
uint16_t tone_delay, tone_spacing;
bool message_available = false;
unsigned int timeout;

// To have the Si5351 produce the I/Q signals below 4.8 MHz, you need to modify the si5351.h
// header so SI5351_PLL_VCO_MIN is 380000000 (380 MHz).
static void set_rx_freq(uint_fast32_t freq)
{
  // Use the Si5351 to produce the I/Q on CLK0 and CLK1.
  rx_freq = freq; // Assuming this does not fail.  Probably should add some error checking.
  uint64_t pll_freq;
  uint_fast8_t mult;
  // mult must be less than 128 (7 bits) according to documentation
  if (freq >= 26470588)
  {
    mult = 22;
  }
  else if (freq >= 18000000)
  {
    mult = 34;
  }
  else if (freq > 12000000)
  {
    mult = 50;
  }
  else if (freq >= 8000000)
  {
    mult = 75;
  }
  else if (freq > 5357143)
  {
    mult = 112;
  }
  else
  {
    mult = 126;
  }
  pll_freq = (uint64_t)mult * freq;
  // Serial.printf("Setting RX frequency to %d Hz\n", freq);
  // Serial.printf("PLL frequency is %llu Hz\n", pll_freq);
  si5351.set_freq_manual(freq * 100ULL * CAL_FACTOR, pll_freq * 100ULL, SI5351_CLK0);
  si5351.set_freq_manual(freq * 100ULL * CAL_FACTOR, pll_freq * 100ULL, SI5351_CLK1);
  // Now we can set CLK1 to have a 90 deg phase shift by entering
  // mult in the CLK1 phase register, since the ratio of the PLL to
  // the clock frequency is mult.
  si5351.set_phase(SI5351_CLK0, 0);
  si5351.set_phase(SI5351_CLK1, mult);
  // We need to reset the PLL before they will be in phase alignment
  si5351.pll_reset(SI5351_PLLA);
}

void tx()
{
  if (useUDP)
  {
    data_sending = false;
  }
  digitalWrite(RX_SWITCH, LOW);    // Set TX mode on T/R switch
  digitalWrite(LED_BUILTIN, HIGH); // Turn on the LED
  digitalWrite(SMPS_ENABLE, HIGH); // Turn on the SMPS for higher power
  delay(100);
  rx_relay_state = 0;
  si5351.output_enable(SI5351_CLK2, 1);
  tx_state = 1;
}

void rx()
{ // Do we really need two functions for rx and tx? maybe a parameter?
  if (useUDP)
  {
    data_sending = true;
  }
  si5351.output_enable(SI5351_CLK2, 0);
  tx_state = 0;
  digitalWrite(RX_SWITCH, HIGH);
  digitalWrite(LED_BUILTIN, LOW); // Turn off the LED
  rx_relay_state = 1;
  digitalWrite(SMPS_ENABLE, LOW); // Turn off the SMPS for lower noise (perhaps)
}

void set_tx_freq(uint32_t freq)
{
  // Let driver choose PLL settings. May glitch when changing frequencies.
  tx_freq = freq;
  // Serial.print("Setting TX frequency to ");
  // Serial.println(tx_freq);
  si5351.set_freq(tx_freq * 100ULL * CAL_FACTOR, SI5351_CLK2);
}

// Loop through the string, transmitting one character at a time.
void transmit()
{
  uint8_t i;
  unsigned long digital_tx_freq;
  digital_tx_freq = tx_freq + offset;
  // Reset the tone to the base frequency and turn on the output
  tx();
  // Now transmit the channel symbols
  if (cur_mode == MODE_FSQ_2 || cur_mode == MODE_FSQ_3 || cur_mode == MODE_FSQ_4_5 || cur_mode == MODE_FSQ_6)
  {
    uint8_t j = 0;
    while (tx_buffer[j++] != 0xff)
      ;
    symbol_count = j - 1;
  }
  for (i = 0; i < symbol_count; i++)
  {
    si5351.set_freq((digital_tx_freq) * 100ULL + (tx_buffer[i] * tone_spacing), SI5351_CLK2);
    delay(tone_delay);
  }
  // Back to receive
  Serial.println("Transmitting complete.");
  delay(100);
  rx();
}

void setup_mode(enum mode sel_mode)
{
  // Set the proper frequency, tone spacing, symbol count, and
  // tone delay depending on mode
  switch (sel_mode)
  {
  case MODE_JT9:
    tx_freq = JT9_DEFAULT_FREQ;
    symbol_count = JT9_SYMBOL_COUNT; // From the library defines
    tone_spacing = JT9_TONE_SPACING;
    tone_delay = JT9_DELAY;
    break;
  case MODE_JT65:
    tx_freq = JT65_DEFAULT_FREQ;
    symbol_count = JT65_SYMBOL_COUNT; // From the library defines
    tone_spacing = JT65_TONE_SPACING;
    tone_delay = JT65_DELAY;
    break;
  case MODE_JT4:
    tx_freq = JT4_DEFAULT_FREQ;
    symbol_count = JT4_SYMBOL_COUNT;
    tone_spacing = JT4_TONE_SPACING;
    tone_delay = JT4_DELAY;
    break;
  case MODE_WSPR:
    tx_freq = WSPR_DEFAULT_FREQ;
    symbol_count = WSPR_SYMBOL_COUNT; // From the library defines
    tone_spacing = WSPR_TONE_SPACING;
    tone_delay = WSPR_DELAY;
    break;
  case MODE_FT8:
    tx_freq = FT8_DEFAULT_FREQ;      // At this point, we are letting Quisk & WJST-X set the frequency. Maybe delete these.
    symbol_count = FT8_SYMBOL_COUNT; // From the library defines
    tone_spacing = FT8_TONE_SPACING;
    tone_delay = FT8_DELAY;
    break;
  case MODE_FT4:
    tx_freq = FT4_DEFAULT_FREQ;
    symbol_count = FT4_SYMBOL_COUNT;
    tone_spacing = FT4_TONE_SPACING;
    tone_delay = FT4_DELAY;
    break;
  case MODE_FSQ_2:
    tx_freq = FSQ_DEFAULT_FREQ;
    tone_spacing = FSQ_TONE_SPACING;
    tone_delay = FSQ_2_DELAY;
    break;
  case MODE_FSQ_3:
    tx_freq = FSQ_DEFAULT_FREQ;
    tone_spacing = FSQ_TONE_SPACING;
    tone_delay = FSQ_3_DELAY;
    break;
  case MODE_FSQ_4_5:
    tx_freq = FSQ_DEFAULT_FREQ;
    tone_spacing = FSQ_TONE_SPACING;
    tone_delay = FSQ_4_5_DELAY;
    break;
  case MODE_FSQ_6:
    tx_freq = FSQ_DEFAULT_FREQ;
    tone_spacing = FSQ_TONE_SPACING;
    tone_delay = FSQ_6_DELAY;
    break;
  }
}

uint8_t si5351_init()
{
  si5351.init(SI5351_CRYSTAL_LOAD_8PF, 0, 0);
  si5351.set_pll(SI5351_PLL_FIXED, SI5351_PLLA);
  // Set output frequencies
  set_rx_freq(rx_freq);
  set_tx_freq(tx_freq);
  // Enable RX, and disable TX by default.
  si5351.output_enable(SI5351_CLK0, 1);
  si5351.output_enable(SI5351_CLK1, 1);
  si5351.output_enable(SI5351_CLK2, 0);
  si5351.drive_strength(SI5351_CLK2, SI5351_DRIVE_8MA); // Set for max power on TX
  // Read the status register and return the chip revision ID.
  si5351.update_status();
  return si5351.dev_status.REVID;
}

I2S i2s(INPUT);

void processCommandUDP()
{
  bool no_error;
  char received = 0;
  String command;

  // Check if there's any serial data available.
  if (Serial.available())
  {
    command = Serial.readStringUntil('\n');
    no_error = true;
    // Process the received command
    if (command.startsWith("VER"))
    {
      useUDP = false; // Set useUDP to false if the UART gives us a VER command.
      Serial.printf("VER, %s\r\n", VERSION_NUMBER);
    }
    return;
  }
  int command_packetSize = udpCommand.parsePacket();
  if (command_packetSize)
  {
    char command_packetBuffer[UDP_TX_PACKET_MAX_SIZE];
    int len = udpCommand.read(command_packetBuffer, UDP_TX_PACKET_MAX_SIZE);
    if (len > 0)
    {
      command_packetBuffer[len] = 0; // Null terminate the string.
      received = command_packetBuffer[0];
    }
    command = String(command_packetBuffer);
    no_error = true;
    // UART Prints for debugging.  Eventually take all the Serial.prints out of this function.
    Serial.print("Received packet of size ");
    Serial.println(len);
    Serial.print("From ");
    Serial.print(udpCommand.remoteIP());
    Serial.print(", port ");
    Serial.println(udpCommand.remotePort());
    Serial.print("Message: ");
    Serial.println(command);
    // Process the received command
    quiskIP = udpCommand.remoteIP();
    Serial.print("received is ");
    Serial.println(received);
    if ((received == 'm') || // This whole if statement is a way of combining my code with
        (received == 'o') || // wsjt-transceiver.ino.  I'm not sure if it is the best way,
        (received == 'e') || // but it seperates the wsjt-x commands from the original commands..
        (received == 'w') ||
        (received == 't') ||
        (received == 'p') ||
        (received == 'r') ||
        (received == 'f') ||
        (received < 32)) // Check for a message which is a control character in ASCII.
    {
      // New message
      if (received == 'm')
      {
        Serial.println("Received an m.");
        int packetSize = udpCommand.parsePacket();
        if (packetSize)
        {
          // If there's a packet available, read it into a buffer
          int len = udpCommand.read(tx_buffer, 255);
          if (len == symbol_count)
          {
            tx_buffer[len] = 0;
            Serial.println((char *)tx_buffer);
          }
          else
          {
            Serial.println("Packet was not symbol_count bytes long.");
          }
        }
        message_available = true;
        udpCommand.write("m");
      }
      // Change offset
      else if (received == 'o')
      {
        char incomingPacket[255];
        // Serial.println("Received an o.");
        // Offset encoded in two bytes
        int packetSize = udpCommand.parsePacket();
        if (packetSize)
        {
          // If there's a packet available, read it into a buffer
          int len = udpCommand.read(incomingPacket, 255);
          if (len == 2)
          {
            incomingPacket[len] = 0;
          }
          else
          {
            Serial.println("Offset packet was not 2 bytes long.");
          }
        }
        offset = (incomingPacket[0]) + (incomingPacket[1] << 8);
        udpCommand.write("o");
        // Serial.println("Wrote o.");
      }

      // Switch mode = FT8  Note: We start in FT8 mode and don't sync until a change mode is sent.
      else if (received == 'e')
      {
        cur_mode = MODE_FT8;
        setup_mode(cur_mode);
        udpCommand.write("e");
        message_available = false;
      }
      // Switch mode = FT4
      else if (received == 'f')
      {
        cur_mode = MODE_FT4;
        setup_mode(cur_mode);
        udpCommand.write("f");
        message_available = false;
      }
      // WSPR Mode
      else if (received == 'w')
      {
        cur_mode = MODE_WSPR;
        setup_mode(cur_mode);
        message_available = false;
      }
      // Transmit
      else if (received == 't')
      {
        if (message_available)
          transmit();
      }
      // Pre transmit
      else if (received == 'p')
      {
        // tx_enable();  Don't need this.
      }
      else if (received == 'r')
      {
        // Send indication for ready!
        udpCommand.write("r");
      }
    }
    else
    {
      if (command.startsWith("VER")) // Whatever way we get VER, sets useUDP.
      {
        udpCommand.beginPacket(quiskIP, udpCommand.remotePort());
        Serial.println("VER received!");
        Serial.println("Began Packet.");
        Serial.printf("VER,%s\r\n", VERSION_NUMBER);
        udpCommand.printf("VER,%s\r\n", VERSION_NUMBER);
        udpCommand.endPacket();
        useUDP = true; // Set useUDP to true
        // Determine whether to use UDP or UART.
      }
      else if (command.startsWith("START_I2S_UDP"))
      {
        Serial.println("START_I2S_UDP received!");
        data_sending = true;
        udpData.begin(DATA_UDPPORT); // Initialize UDP for data port
        i2s.begin();
      }
      else if (command.startsWith("STOP"))
      {
        Serial.println("STOP received!");
        data_sending = false;
        udpData.stop();
        i2s.end();
      }
      else if (command.startsWith("FREQ"))
      {
        Serial.println("FREQ received!");
        int commaIndex = command.indexOf(',');
        if (commaIndex != -1)
        {
          String freqStr = command.substring(commaIndex + 1);
          uint32_t freq = freqStr.toInt();
          set_rx_freq(freq);
          set_tx_freq(freq);
          udpCommand.beginPacket(quiskIP, udpCommand.remotePort());
          udpCommand.printf("FREQ,%ld\r\n", freq);
          udpCommand.endPacket();
        }
        else
        {
          udpCommand.beginPacket(quiskIP, udpCommand.remotePort());
          udpCommand.printf("FREQ,%u\r\n", rx_freq);
          udpCommand.endPacket();
        }
      }
      else if (command.startsWith("TX_FREQ"))
      {
        Serial.println("TX_FREQ received!");
        int commaIndex = command.indexOf(',');
        if (commaIndex != -1)
        {
          String freqStr = command.substring(commaIndex + 1);
          uint32_t freq = freqStr.toInt();
          set_tx_freq(freq);
          udpCommand.beginPacket(quiskIP, udpCommand.remotePort());
          udpCommand.printf("TX_FREQ,%ld\r\n", freq);
          udpCommand.endPacket();
        }
        else
        {
          udpCommand.beginPacket(quiskIP, udpCommand.remotePort());
          udpCommand.printf("TX_FREQ,%d\r\n", tx_freq);
          udpCommand.endPacket();
        }
      }
      else if (command.startsWith("USE_UART"))
      {
        useUDP = false; // Set useUDP to false
        data_sending = false;
        udpCommand.beginPacket(quiskIP, udpCommand.remotePort());
        udpCommand.printf("USE_UART\r\n");
        udpCommand.endPacket();
      }
      else if (command.startsWith("TX"))
      {
        Serial.println("TX received!");
        tx();
        udpCommand.beginPacket(quiskIP, udpCommand.remotePort());
        udpCommand.printf("TX\r\n");
        udpCommand.endPacket();
      }
      else if (command.startsWith("RX"))
      {
        Serial.println("RX received!");
        rx();
        udpCommand.beginPacket(quiskIP, udpCommand.remotePort());
        udpCommand.printf("RX\r\n");
        udpCommand.endPacket();
      }
      else
      {

        Serial.println("Unknown command received!");
        udpCommand.beginPacket(quiskIP, udpCommand.remotePort());
        udpCommand.write("ERROR\r\n");
        udpCommand.endPacket();
        no_error = false;
      }
    }
    if (no_error)
    {
      udpCommand.beginPacket(quiskIP, udpCommand.remotePort());
      udpCommand.write("OK\r\n"); // Do we need an Ok after an error?
      udpCommand.endPacket();
    }
  }
}
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
void loop()
{
  // Serial.printf("In loop, useUDP is %d\n", useUDP);
  if (useUDP)
  {
    processCommandUDP();
  }
  else
  {
    processCommandUART();
    // Serial.println("processCommandUART done.");
  }
  if (data_sending)
  {
    // This should run on Core0.  It is the UDP loop.
    static BufferEmptyer emptyer(bufferQueue);
    emptyer.emptyBuffer(); // Empty the buffer
  }
}

void loop1()
{ // This should run on Core1.  It is the I2S loop.
  if (useUDP)
  {
    // Serial.printf("In loop1.\n");
    if (data_sending)
    {
      static BufferFiller filler(bufferQueue);
      filler.fillBuffer(); // Fill the buffer
    }
  }
}

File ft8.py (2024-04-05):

#!/usr/local/bin/python

#
# encode and decode FT8.
#
# for new 77-bit FT8.
# LDPC tables and pack/unpack details from wsjt-x 2.0.
#
# Robert Morris, AB1HL
#

import numpy
import wave
import scipy
import scipy.signal
import sys
import os
import math
import time
import multiprocessing
import threading
import re
import random
import ctypes
#import weakaudio
#import weakutil

#
# tuning parameters.
#
budget = 2.2 # max seconds of time for decoding.
pass0_fstep = 2 # coarse search granularity, per FFT bin
pass0_tstep = 2 # coarse search granularity, per symbol time
passN_fstep = 2 # coarse search granularity, per FFT bin
passN_tstep = 4 # coarse search granularity, per symbol time
pass0_tminus = 2.2 # start search this many seconds before 0.5
pass0_tplus = 2.7 # end search this many seconds after 0.5
passN_tminus = 1.5
passN_tplus = 1.8
coarse_no    = 1 # number of best offsets to use per hz
fine_no    = 1 # number of best fine offsets to look at
fine_fstep = 4 # fine-tuning steps per coarse_fstep
fine_tstep = 8 # fine-tuning steps per coarse_tstep
start_adj = 0.1 # signals seem on avg to start this many seconds late.
ldpc_iters = 30 # how hard LDPC should work on pass 0
softboost = 1.0 # log(prob) if #2 symbol has same bit value
do_subtract = 1 # 0 none, 1 once per unique decode, 2 three per unique, 3 once per decode
subgap = 0.8  # extra subtract()s this many hz on either side of main bin
substeps = 16 # subtract phase steps, in 2pi
subpasses = 2 # 0 means no subtraction, 1 means subtract, 2 means another subtraction pass
pass0_frac = 1.0
pass0_hints = True # hints in pass 0 (as well as later passes)?
contrast_weight = 0.5
noise_factor = 0.8 # for strength()
top_high_order = 0 # 0 for cheby, 19 for butter
high_cutoff = 1.05
low_pass_order = 0 # 15
top_down = True
bottom_slow = True
osd_crc = False # True means OSD only accepts if CRC is correct
osd0_crc = True # True means OSD accepts if depth=0 CRC is correct
osd_depth = 6
osd_thresh = -500
already_o = 1
already_f = 1
down200 = False # process1() that down-converts to 200 hz / 32 samples/symbol
use_apriori = True
nchildren = 4
child_overlap = 30
osd_no_snr = False
padfactor = 0.1 # quiet-ish before/after padding
osd_hints = False # use OSD on hints BUT causes lots of false pseudo-juicy CQs!
down_cutoff = 0.45 # low-pass filter cutoff before down-sampling
cheb_cut1 = 0.48
cheb_cut2 = 0.61
cheb_ripple_pass = 0.5
cheb_atten_stop = 50
cheb_high_minus = 40
cheb_high_plus = 60
hint_tol = 9 # look for CQ XXX hints in this +/- hz range of where heard
crc_and_83 = True # True means require both CRC and LDPC
ldpc_thresh = 83 # 83 means all LDPC check-bits must be correct
snr_overlap = 3 # -1 means don't convert to snr, 0 means each sym time by itself
snr_wintype = "blackman"
real_min_hz = 150
real_max_hz = 2900
sub_amp_win = 2
adjust_hz_for_sub = True
adjust_off_for_sub = True
yes_mul = 1.0
yes_add = 0.0
no_mul = 1.0
no_add = 0.0
soft1 = 7
soft2 = 8
soft3 = 4
soft4 = 6
guard200 = 10
order200 = 5
strength_div = 4.0
decimate_order = 8

# FT8 modulation and protocol definitions.
# 1920-point FFT at 12000 samples/second
#   yields 6.25 Hz spacing, 0.16 seconds/symbol
# encode chain:
#   77 bits
#   append 14 bits CRC (for 91 bits)
#   LDPC(174,91) yields 174 bits
#   that's 58 3-bit FSK-8 symbols
#   gray code each 3 bits
#   insert three 7-symbol Costas sync arrays
#     at symbol #s 0, 36, 72 of final signal
#   thus: 79 FSK-8 symbols
# total transmission time is 12.64 seconds
# Agrees with https://wsjt.sourceforge.io/FT4_FT8_QEX.pdf

costas_symbols = [ 3, 1, 4, 0, 6, 5, 2 ] # new FT8

# gray map for encoding 3-bit chunks of the 174 bits,
# after LDPC and before generating FSK-8 tones.
graymap = [ 0, 1, 3, 2, 5, 6, 4, 7 ]

# the CRC-14 polynomial, from wsjt-x's 0x2757,
# with leading 1 bit.
crc14poly = [ 1,   1, 0,   0, 1, 1, 1,   0, 1, 0, 1,   0, 1, 1, 1 ]

def crc_c(msg):
    msgtype = ctypes.c_int * len(msg)
    outtype = ctypes.c_int * 14

    msg1 = msgtype()
    for i in range(0, len(msg)):
        msg1[i] = msg[i]

    out1 = outtype()

    libldpc.ft8_crc(msg1, len(msg), out1)

    out = numpy.zeros(14, dtype=numpy.int32)
    for i in range(0, 14):
        out[i] = out1[i]

    return out

#
# thank you, evan sneath.
# https://gist.github.com/evansneath/4650991
#
# generate with x^3 + x + 1:
#   >>> xc.crc([1, 1, 0, 1, 0, 0, 1, 1, 1, 0, 1, 1, 0, 0], [1, 0, 1, 1])
#   array([1, 0, 0])
# check:
#   >>> xc.crc([1, 1, 0, 1, 0, 0, 1, 1, 1, 0, 1, 1, 0, 0], [1, 0, 1, 1], [1, 0, 0])
#   array([0, 0, 0])
#
# 0xc06 is really 0x1c06 or [ 1, 1, 1, 0, 0, 0, 0, 0, 0, 0, 1, 1, 0 ]
#
def crc_python(msg, div, code=None):
    """Cyclic Redundancy Check
    Generates an error detecting code based on an inputted message
    and divisor in the form of a polynomial representation.
    Arguments:
        msg: The input message of which to generate the output code.
        div: The divisor in polynomial form. For example, if the polynomial
            of x^3 + x + 1 is given, this should be represented as '1011' in
            the div argument.
        code: This is an option argument where a previously generated code may
            be passed in. This can be used to check validity. If the inputted
            code produces an outputted code of all zeros, then the message has
            no errors.
    Returns:
        An error-detecting code generated by the message and the given divisor.
    """

    # Append the code to the message. If no code is given, default to '000'
    if code is None:
        code = numpy.zeros(len(div)-1, dtype=numpy.int32)
    assert len(code) == len(div) - 1
    msg = numpy.append(msg, code)

    div = numpy.array(div, dtype=numpy.int32)
    divlen = len(div)

    # Loop over every message bit (minus the appended code)

    for i in range(len(msg)-len(code)):
        # If that messsage bit is 1, perform modulo 2 multiplication
        if msg[i] == 1:
            #for j in range(len(div)):
            #    # Perform modulo 2 multiplication on each index of the divisor
            #    msg[i+j] = (msg[i+j] + div[j]) % 2
            msg[i:i+divlen] = numpy.mod(msg[i:i+divlen] + div, 2)

    # Output the last error-checking code portion of the message generated
    return msg[-len(code):]

def crc(msg, div):
    if True:
        return crc_c(msg)
    else:
        return crc_python(msg, div)

def check_crc(a91):
    padded = numpy.append(a91[0:77], numpy.zeros(5, dtype=numpy.int32))
    cksum = crc(padded, crc14poly)
    if numpy.array_equal(cksum, a91[-14:]) == False:
        # CRC failed.
        return False
    return True
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

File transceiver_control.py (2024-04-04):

import datetime
import time
import serial
import struct
import os
import yaml
from consolemenu import *
from consolemenu.items import *
import sys

from ft8 import FT8Send
from ft4 import FT4Send

# Import weakmon to use encoders
sys.path.append(os.path.expandvars('$WEAKMON'))

# Read configuration file
configs_file = open('transceiver_config.yml', 'r')
configs = yaml.safe_load(configs_file)

# Serial port for arduino
serial_port = configs['serial_port']
baudrate = configs['baudrate']
try:
    puerto = serial.Serial(serial_port, baudrate, timeout=0.5)
except serial.serialutil.SerialException as e:
    print("\nCannot connect to the serial port: " + serial_port + "\n")
    exit(1)

# Global variables
callsign = configs['callsign']
grid = configs['grid']
current_msg = ''
rx_callsign = ''
mode = 'FT8'

# FT8 encoder
ft8_encoder = FT8Send()
ft4_encoder = FT4Send()

def encode_ft8(msg):
    try:
        a77 = ft8_encoder.pack(msg, 1)
        symbols = ft8_encoder.make_symbols(a77)
    except Exception as e:
        print("FT8 encoder error:", e)
        symbols = None
        time.sleep(3)
    return symbols

def encode_ft4(msg):
    try:
        a77 = ft4_encoder.pack(msg, 1)
        symbols = ft4_encoder.make_symbols(a77)
    except:
        print("FT4 encoder error, check message!")
        symbols = None
        time.sleep(3)
    return symbols

def load_symbols(symbols):
    print("Load symbols into transmitter..")
    puerto.write(b'm')
    for symbol in symbols:
        puerto.write(struct.pack('>B', symbol))
    puerto.write(b'\0')
    time.sleep(1)

def change_freq():
    no_freq = True
    while(no_freq):
        new_freq = int(input("Enter new offset frequency (0 - 2000Hz): "))
        if (new_freq > 0 and new_freq < 2000):
            no_freq = False
    puerto.write(b'o')
    for kk in range(2):
        puerto.write(struct.pack('>B', (new_freq >> 8*kk) & 0xFF))
    time.sleep(1)

def change_mode():
    global mode
    global current_msg
    if 'FT8' in mode:
        print("Switch mode to FT4!")
        menu.remove_item(chft4_item)
        menu.append_item(chft8_item)
        mode = 'FT4'
    else:
        print("Switch mode to FT8!")
        menu.remove_item(chft8_item)
        menu.append_item(chft4_item)
        mode = 'FT8'
    puerto.write(b's')
    current_msg = ''
    time.sleep(1)
    menu.show()

def change_udp():
    print("Switch to UDP mode!")
    puerto.write(b'u')
    time.sleep(1)
    menu.show()

def new_msg(msg):
    global current_msg
    global mode
    print(msg)
    if msg != current_msg:
        if 'FT8' in mode:
            symbols = encode_ft8(msg)
        else:
            symbols = encode_ft4(msg)
        if symbols is not None:
            load_symbols(symbols)
            current_msg = msg
        else:
            return
    transmit()

def transmit():
    if not current_msg:
        print("No previous message!")
        time.sleep(1)
    else:
        print("Waiting for slot..")
        while True:
            utc_time = datetime.datetime.now(datetime.timezone.utc)
            if 'FT8' in mode:
                if (utc_time.second % 15 == 14):
                    print("TX!")
                    puerto.write(b't')
                    time.sleep(1)
                    break
            else:
                mscount = utc_time.second + utc_time.microsecond/1e6
                if (abs(mscount%7.5 - 6.5) < 0.05):
                    print("TX!")
                    puerto.write(b't')
                    time.sleep(1)
                    break

def call_cq():
    msg = 'CQ ' + callsign + ' ' + grid
    new_msg(msg)

def resp_new():
    global rx_callsign
    rx_callsign = input("Respond to callsign: ")
    resp_submenu.show()

def resp_last():
    if not rx_callsign:
        print("No previous callsign!")
        time.sleep(1)
    else:
        resp_submenu.show()

def respond(response):
    if 'grid' in response:
        msg = rx_callsign + ' ' + callsign + ' ' + grid
    elif 'signal' in response:
        snr = input("Signal strength: ")
        msg = rx_callsign + ' ' + callsign + ' ' + snr
    elif 'RR73' in response:
        msg = rx_callsign + ' ' + callsign + ' RR73'
    new_msg(msg)

# Create the menus
menu = ConsoleMenu("WJSTX Transceiver Control ", "FT8 and FT4")
resp_submenu = ConsoleMenu("Respond with: ", "", exit_option_text="Go back")

# Main menu
ver_item = FunctionItem("Use UART, not UDP", change_udp, [])
cq_item = FunctionItem("Call CQ", call_cq, [])
retransmit_item = FunctionItem("Retransmit last", transmit, [])
resp_new_item = FunctionItem("Respond to new callsign", resp_new, [])
submenu_item = FunctionItem("Respond to last callsign", resp_last, [])
chfreq_item = FunctionItem("Change TX frequency", change_freq, [])
chft4_item = FunctionItem("Change mode to FT4", change_mode, [])
chft8_item = FunctionItem("Change mode to FT8", change_mode, [])

# Resp submenu
resp_grid_item = FunctionItem("Respond with grid", respond, ['grid'])
resp_signal_item = FunctionItem("Respond with R + signal strength", respond, ['signal'])
resp_73_item = FunctionItem("Respond with RR73", respond, ['RR73'])

resp_submenu.append_item(resp_grid_item)
resp_submenu.append_item(resp_signal_item)
resp_submenu.append_item(resp_73_item)

menu.append_item(ver_item)
menu.append_item(cq_item)
menu.append_item(resp_new_item)
menu.append_item(submenu_item)
menu.append_item(retransmit_item)
menu.append_item(chfreq_item)
menu.append_item(chft4_item)
menu.show()

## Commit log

2024-05-13 May 13, 2024, 12:09 PM
    [Receiver.kicad_sch]
2024-05-19 May 19, 2024, 1:57 PM
    [SDR-TRX.kicad_sch]
2024-07-01 Jul 1, 2024, 1:31 PM
    [PA.kicad_sch, Receiver.kicad_sch, SDR-TRX.kicad_pcb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]
2025-01-06 Set MD0 and MD1 low for slave mode.
    [SDR-TRX.kicad_pcb]
